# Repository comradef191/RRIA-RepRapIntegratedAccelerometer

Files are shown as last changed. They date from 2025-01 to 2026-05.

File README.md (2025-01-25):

# Duet3D-Accelerometer
A standalone accelerometer board using the LIS3DH(v0.2) or LIS2DW12(v1.0) MEMS digital motion sensor. It is designed to plug into the SPI daughterboard header on Duet 2 and 3 mainboards.

Duet_3_Accelerometer_02_s_9f60be45_thumbnail_256 1

Product Page:
[https://www.duet3d.com/duet3d-accelerometer](https://www.duet3d.com/duet3d-accelerometer)

Documentation is here:

[Duet 3 Accelerometer Documentation](https://docs.duet3d.com/en/Duet3D_hardware/Accessories/Duet3D_Accelerometer)

licensed under the "CERN-OHL-S v2" or any later version plus the "Additional Duet3D Licence Terms",
see https://github.com/Duet3D/Duet3-Mainboard-6HC/blob/master/LICENSE

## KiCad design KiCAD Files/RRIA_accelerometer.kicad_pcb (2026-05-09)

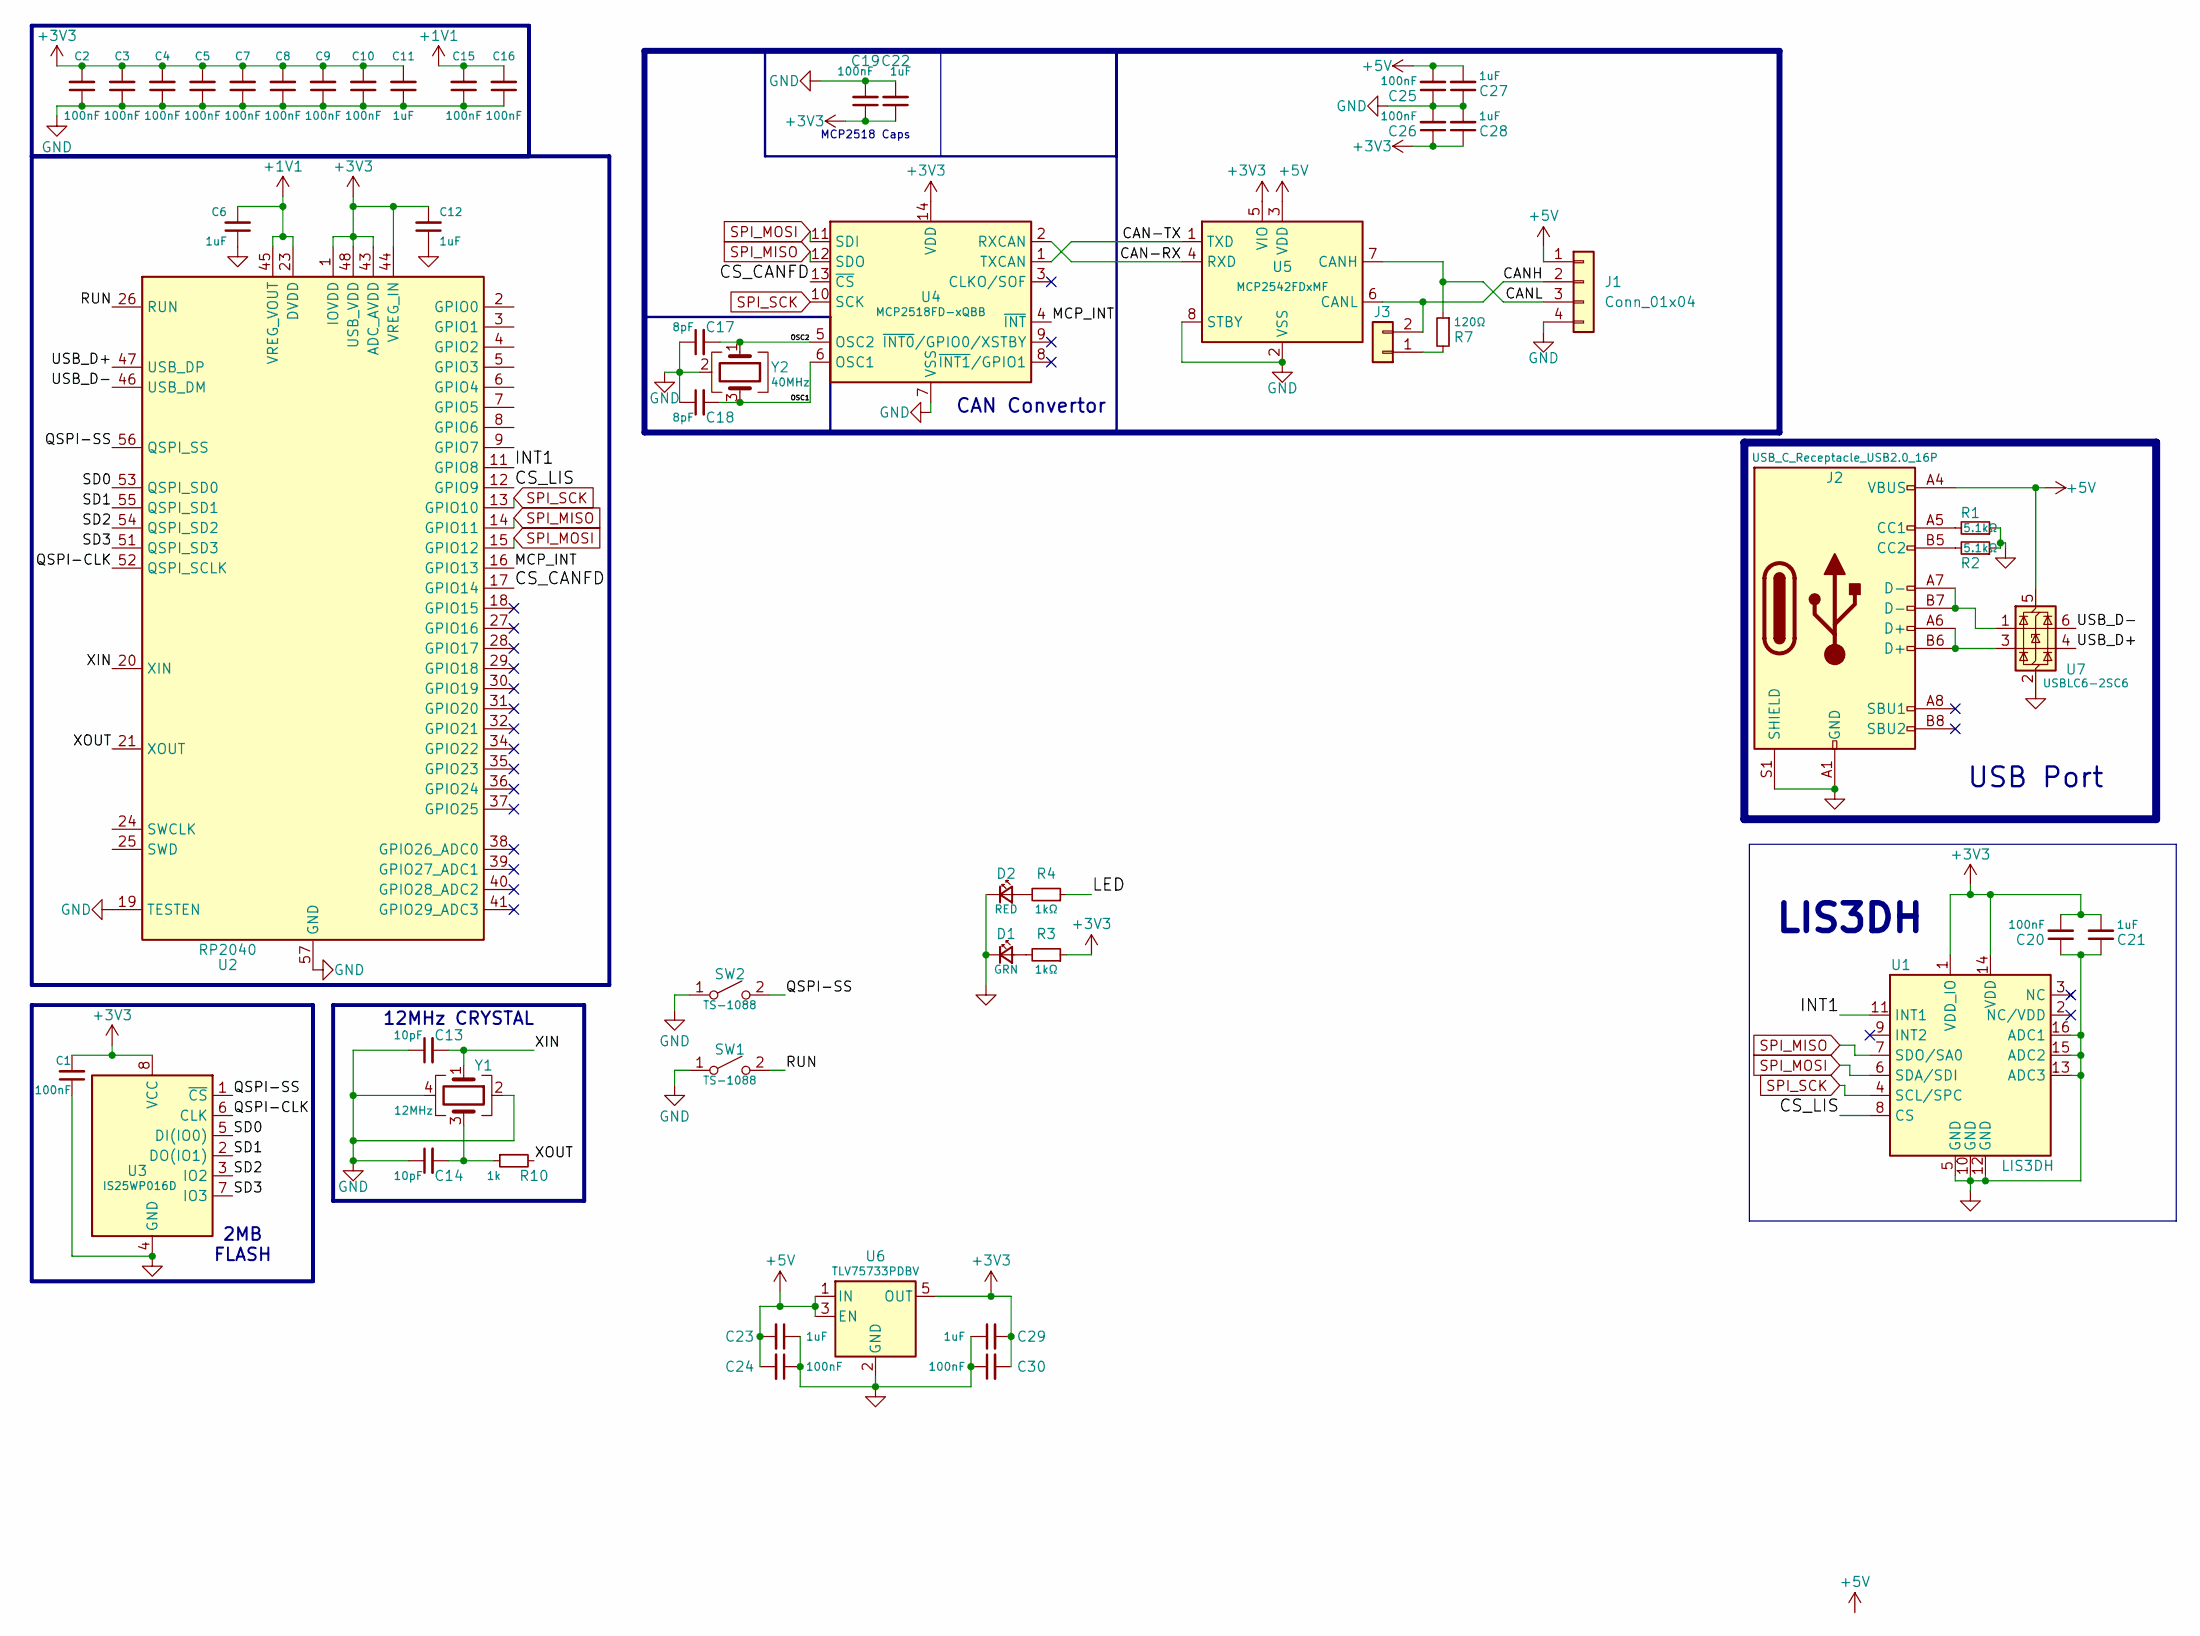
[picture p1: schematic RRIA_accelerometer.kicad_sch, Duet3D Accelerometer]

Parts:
C1, C2, C3, C4, C5, C7, C8, C9, C10, C15, C16: 100nF; C_0402_1005Metric
C6, C11, C12: 1uF; C_0402_1005Metric
C13, C14: 10pF; C_0402_1005Metric
C17, C18: 8pF; C_0402_1005Metric
C19, C20, C25, C26: 100nF; C_0402_1005Metric; LCSC C541464
C21, C22, C27, C28: 1uF; C_0402_1005Metric; LCSC C2887020
C23, C29: 1uF; C_0402_1005Metric; LCSC C52923
C24, C30: 100nF; C_0402_1005Metric; LCSC C1525
D1: GRN; LED_0805_2012Metric; LCSC C2297
D2: RED; LED_0805_2012Metric; LCSC C84256
J1: Conn_01x04; JST_XH_S4B-XH-A_1x04_P2.50mm_Horizontal
J2: USB_C_Receptacle_USB2.0_16P; USB_C_Receptacle_HRO_TYPE-C-31-M-12; LCSC C165948
J3: 2.54-Header-1x2; PinHeader_1x02_P2.54mm_Vertical
R1, R2: 5.1kΩ; R_0402_1005Metric; LCSC C25905
R3, R4: 1kΩ; R_0402_1005Metric; LCSC C11702
R7: 120Ω; R_0402_1005Metric; LCSC C25079
R10: 1k; R_0402_1005Metric
SW1, SW2: TS-1088; SW_SPST_TS-1088-xR025; LCSC C720477
U1: LIS3DH; LGA-16_3x3mm_P0.5mm_LISD3H; Part Number LIS3DHTR
U2: RP2040; QFN-56-1EP_7x7mm_P0.4mm_EP3.2x3.2mm_ThermalVias
U3: IS25WP016D; Winbond_USON-8-1EP_3x2mm_P0.5mm_EP0.2x1.6mm; LCSC C2976734
U4: MCP2518FD-xQBB; DFN-14-1EP_3x4.5mm_P0.65mm_EP1.65x4.25mm; LCSC C621395
U5: MCP2542FDxMF; DFN-8-1EP_3x3mm_P0.65mm_EP1.7x2.05mm; LCSC C635109
U6: TLV75733PDBV; SOT-23-5; LCSC C485517
U7: USBLC6-2SC6; SOT-23-6; LCSC C7519
Y1: 12MHz; Crystal_SMD_2520-4Pin_2.5x2.0mm; LCSC C7294610
Y2: 40MHz

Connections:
+1V1: C6.2, C15.2, C16.2, U2.23 (DVDD), U2.45 (VREG_VOUT), U2.50 (DVDD)
+3V3: C1.2, C2.2, C3.2, C4.2, C5.2, C7.2, C8.2, C9.2, C10.2, C11.2, C12.2, C19.1, C20.2, C21.2, C22.1, C26.1, C28.1, C29.2, C30.2, R3.1, U1.1 (VDD_IO), U1.14 (VDD), U2.1 (IOVDD), U2.10 (IOVDD), U2.22 (IOVDD), U2.33 (IOVDD), U2.42 (IOVDD), U2.43 (ADC_AVDD), U2.44 (VREG_IN), U2.48 (USB_VDD), U2.49 (IOVDD), U3.8 (VCC), U4.14 (VDD), U5.5 (VIO), U6.5 (OUT)
+5V: C23.2, C24.2, C25.2, C27.2, J1.1, J2.A4 (VBUS), J2.A9 (VBUS), J2.B4 (VBUS), J2.B9 (VBUS), U5.3 (VDD), U6.1 (IN), U6.3 (EN), U7.5 (VBUS)
/CAN-RX: U4.2 (RXCAN), U5.4 (RXD)
/CAN-TX: U4.1 (TXCAN), U5.1 (TXD)
/CANH: J1.2, J3.2, U5.6 (CANL)
/CANL: J1.3, R7.1, U5.7 (CANH)
/CS_CANFD: U2.17 (GPIO14), U4.13 (~CS)
/CS_LIS: U1.8 (CS), U2.12 (GPIO9)
/INT1: U1.11 (INT1), U2.11 (GPIO8)
/LED: R4.1
/MCP_INT: U2.16 (GPIO13), U4.4 (~INT)
/OSC1: C18.2, U4.6 (OSC1), Y2.3
/OSC2: C17.2, U4.5 (OSC2), Y2.1
/QSPI-CLK: U2.52 (QSPI_SCLK), U3.6 (CLK)
/QSPI-SS: SW2.2 (B), U2.56 (QSPI_SS), U3.1 (~CS)
/RUN: SW1.2 (B), U2.26 (RUN)
/SD0: U2.53 (QSPI_SD0), U3.5 (DI(IO0))
/SD1: U2.55 (QSPI_SD1), U3.2 (DO(IO1))
/SD2: U2.54 (QSPI_SD2), U3.3 (IO2)
/SD3: U2.51 (QSPI_SD3), U3.7 (IO3)
/USB_D+: U2.47 (USB_DP), U7.4 (I/O2)
/USB_D-: U2.46 (USB_DM), U7.6 (I/O1)
/XIN: C13.2, U2.20 (XIN), Y1.1
/XOUT: R10.2, U2.21 (XOUT)
GND: C1.1, C2.1, C3.1, C4.1, C5.1, C6.1, C7.1, C8.1, C9.1, C10.1, C11.1, C12.1, C13.1, C14.1, C15.1, C16.1, C17.1, C18.1, C19.2, C20.1, C21.1, C22.2, C23.1, C24.1, C25.1, C26.2, C27.1, C28.2, C29.1, C30.1, D1.1 (K), D2.1 (K), J1.4, J2.A1 (GND), J2.A12 (GND), J2.B1 (GND), J2.B12 (GND), J2.S1 (SHIELD), R1.1, R2.1, SW1.1 (A), SW2.1 (A), U1.5 (GND), U1.10 (GND), U1.12 (GND), U1.13 (ADC3), U1.15 (ADC2), U1.16 (ADC1), U2.19 (TESTEN), U2.57 (GND), U3.4 (GND), U3.9 (GND), U4.7 (VSS), U4.15 (VSS), U5.2 (VSS), U5.8 (STBY), U5.9 (VSS), U6.2 (GND), U7.2 (GND), Y1.2, Y1.4, Y2.2 (G), Y2.4 (G)
unnamed: C14.2, R10.1, Y1.3
unnamed: D1.2 (A), R3.2
unnamed: D2.2 (A), R4.2
unnamed: J2.A5 (CC1), R1.2
unnamed: J2.B5 (CC2), R2.2
unnamed: J2.A6 (D+), J2.B6 (D+), U7.3 (I/O2)
unnamed: J2.A7 (D-), J2.B7 (D-), U7.1 (I/O1)
unnamed: J3.1, R7.2
SPI_MISO: U1.7 (SDO/SA0), U2.14 (GPIO11), U4.12 (SDO)
SPI_MOSI: U1.6 (SDA/SDI), U2.15 (GPIO12), U4.11 (SDI)
SPI_SCK: U1.4 (SCL/SPC), U2.13 (GPIO10), U4.10 (SCK)

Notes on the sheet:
12MHz CRYSTAL
CAN Convertor
MCP2518 Caps
USB Port
2MB FLASH
LIS3DH

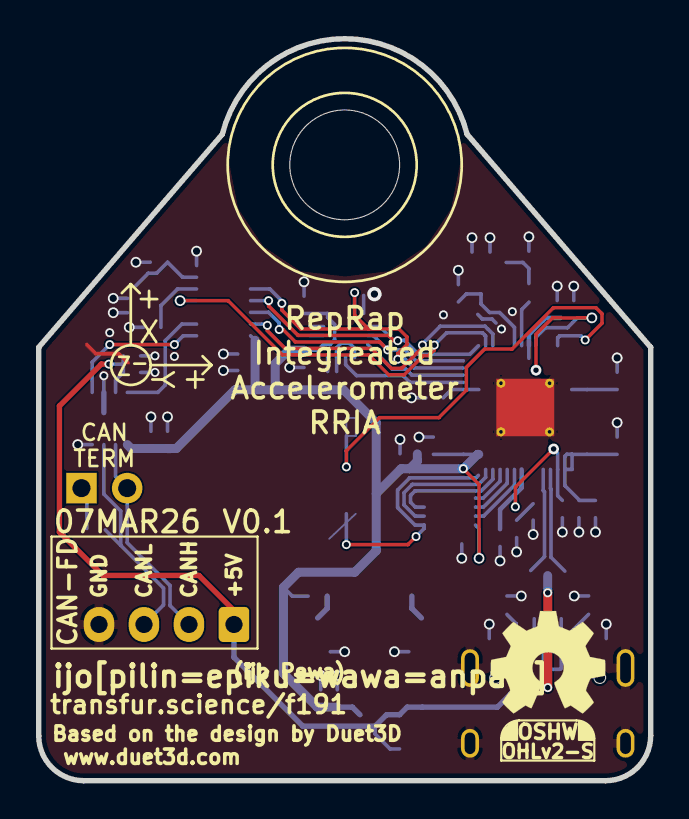
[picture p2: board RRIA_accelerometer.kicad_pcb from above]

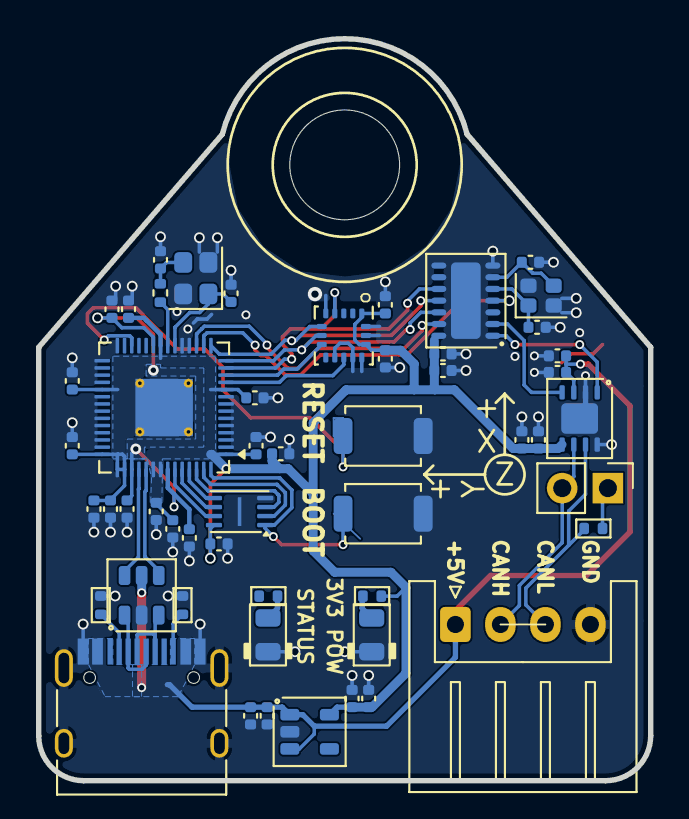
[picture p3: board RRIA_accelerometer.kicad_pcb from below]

Board: 2 copper layers, 34.0 x 41.2 mm, 53 parts (52 on the bottom side), 36 nets.

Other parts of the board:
H1: M6; MountingHole_6mm

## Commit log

2026-04-04 Rename files; Prep
    [Duet3_accelerometer.step, RRIA_accelerometer.kicad_pcb, RRIA_accelerometer.kicad_sch]
2026-04-04 gitignore + prep for RP2040
    [RRIA_accelerometer.kicad_pcb, RRIA_accelerometer.kicad_sch]
